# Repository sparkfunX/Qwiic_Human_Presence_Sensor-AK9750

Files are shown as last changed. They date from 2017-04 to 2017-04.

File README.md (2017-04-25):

Qwiic Human Presence Sensor - AK9750
========================================

Qwiic Human Presence Sensor - AK9750

[*SPX-14289*](https://www.sparkfun.com/products/14289)

The AK9750 is a passive infrared sensor with four discrete sensors built into one digital package. PIRs are most often used in security systems to detect the movement of a human talking through the room. If you've ever seen a 1" white sphere in the corner of a room, that's a PIR. We sell a [simple PIR](https://www.sparkfun.com/products/13285) as well. The problem with PIRs is many fold. The vast majority of PIRs use a simple on/off interface. The AK9750 is a digital sensor giving you a 16-bit digital value over I<sup>2</sup>C. Furthermore, the AK9750 has *four* sensors built in! This allows you to detect not only presence but relative distance and direction of movement (for example: PIR2 went off then PIR4 went off so the human is moving left to right).

Each of the four sensors outputs the IR current in pico-amps (-14,286 to 14,286pA). A PIR reading can vary from roughly -200 (no human present) to 1500 when a human is detected standing in front of a given channel but it varies due to environmental factors and other heat sources in view. We've written a library to control the sensor and included a examples showing how to output the sensor readings. We've also written a Processing sketch to visualize the IR sensor readings in real time. 

The Qwiic Human Presence Sensor - AK9750 is rear mounted through the 0.8mm thick PCB. Additionally, the sensor ships without a lens. We've found the sensor to perform quite well and detect human movement over 10 feet (3 meters) away without the standard Fresnel lens. 

Need many eyes in the sky? The ADR jumpers allow up to 3 sensors on a bus. Need more? Our [Qwiic Mux](https://www.sparkfun.com/products/14257) will enable up to 192 sensors for a total of 768 presence readings. Eeek!

This board includes Qwiic connectors. The [Qwiic system](http://www.sparkfun.com/qwiic) enables fast and solderless connection between popular platforms and various sensors and actuators. You can read more about the Qwiic system [here](http://www.sparkfun.com/qwiic).

Repository Contents
-------------------

* **/Documents** - AK9750 datasheet and graph of movement detection. 
* **/Firmware** - Example sketches for the library (.ino). Run these from the Arduino IDE. 
* **/Hardware** - Source files for the PCB layout in EAGLE (.brd, .sch).
* **/Visualizer** - Processing sketch with matching Arduino sketch to see data on a heat map.

License Information
-------------------

This product is _**open source**_!

Please review the LICENSE.md file for license information.

If you have any questions or concerns on licensing, please contact techsupport@sparkfun.com.

Distributed as-is; no warranty is given.

- Your friends at SparkFun.

_<COLLABORATION CREDIT>_

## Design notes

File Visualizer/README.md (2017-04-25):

AK9750 Visualizer
========================================

AK9750 Visualizer Processing Sketch

The visualizer sketch shows four circles. The brightness of the red is based on the IR readings from the AK9750. This is a good way to see how the sensor responds to humans walking through a scene.

There is one line in the sketch that will need to be adapted to your environment:

    sensorValue[x] = map(float(tempValues[x]), -200, 400, 0, 255);

This line maps an IR reading from -200/400 to 0/255 (allowed red colors). Your sensor readings may be lower than -200 and greater than 400 depending on your environment.

License Information
-------------------

This product is _**open source**_!

Please review the LICENSE.md file for license information.

If you have any questions or concerns on licensing, please contact techsupport@sparkfun.com.

Distributed as-is; no warranty is given.

- Your friends at SparkFun.

_<COLLABORATION CREDIT>_

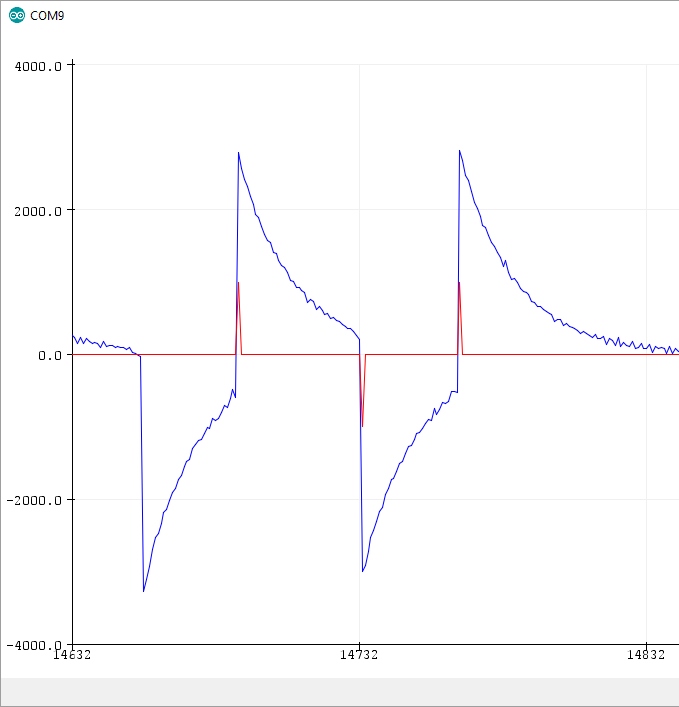
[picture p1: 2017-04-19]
Documents/Presence-Graph.jpg

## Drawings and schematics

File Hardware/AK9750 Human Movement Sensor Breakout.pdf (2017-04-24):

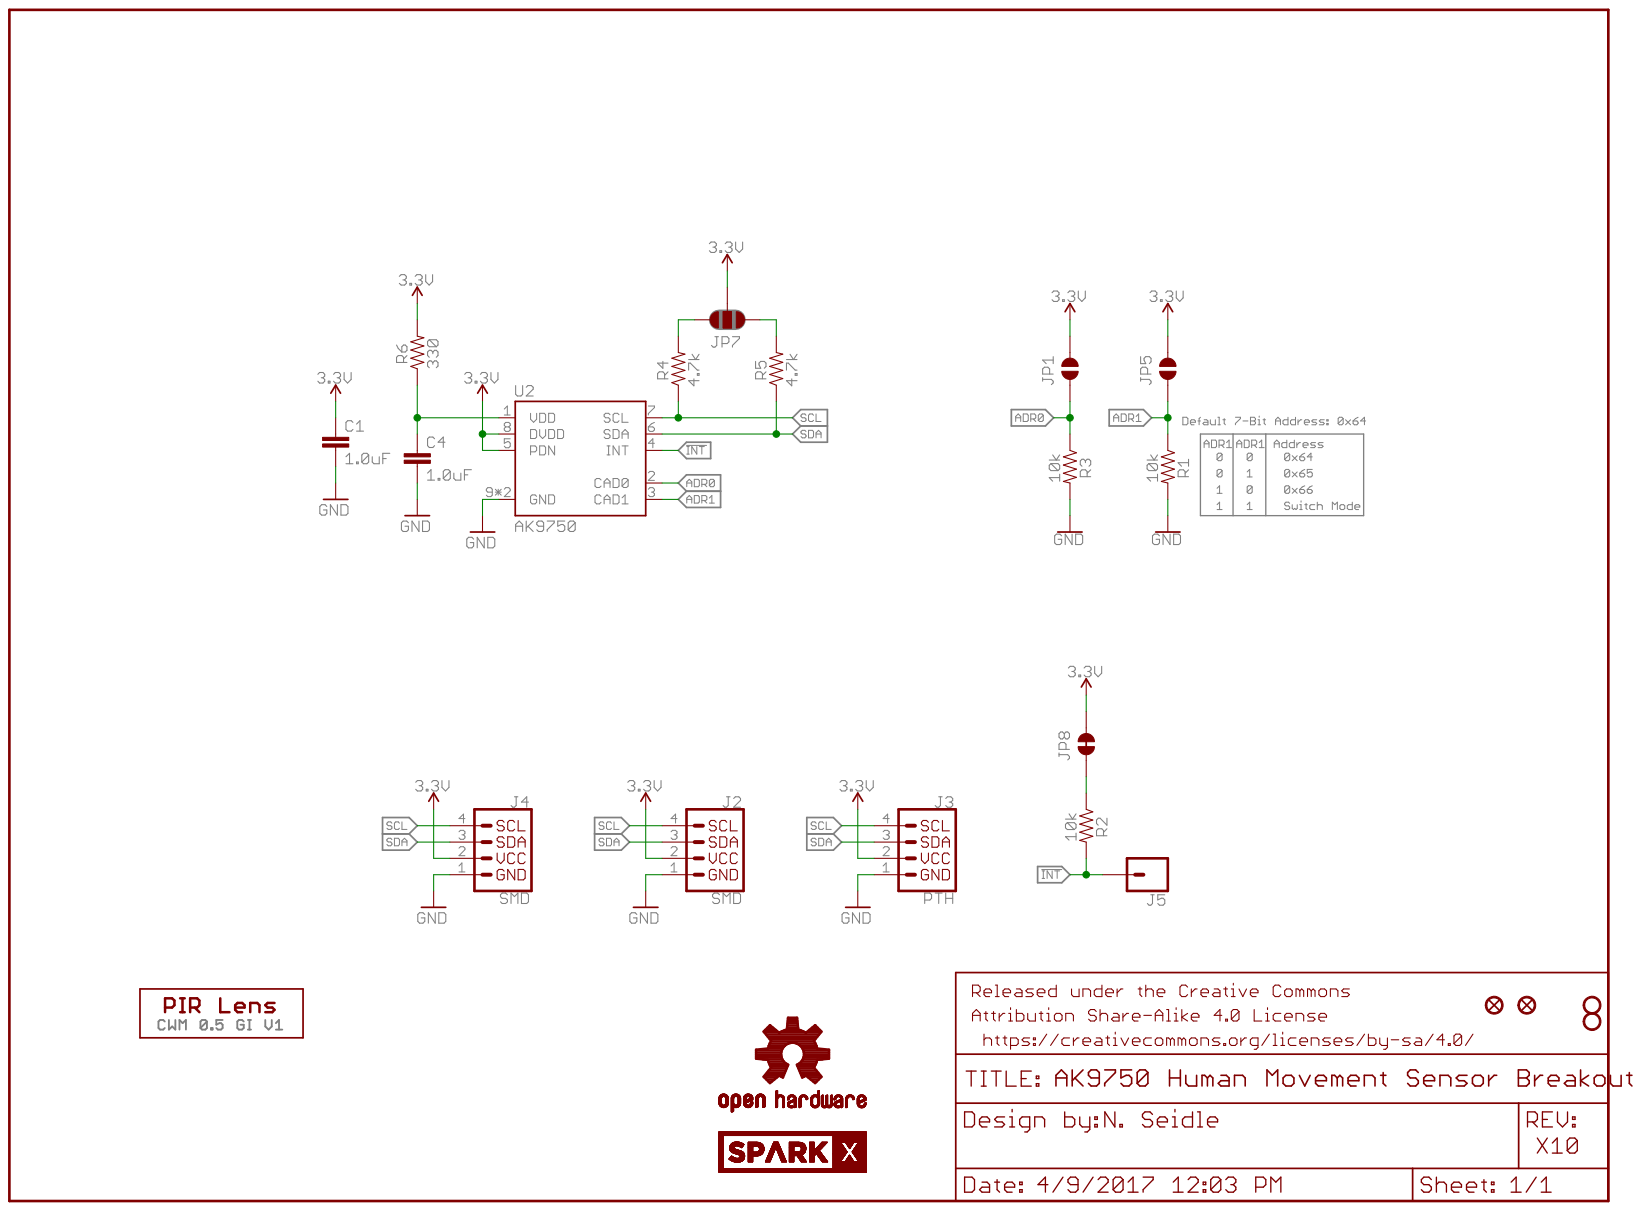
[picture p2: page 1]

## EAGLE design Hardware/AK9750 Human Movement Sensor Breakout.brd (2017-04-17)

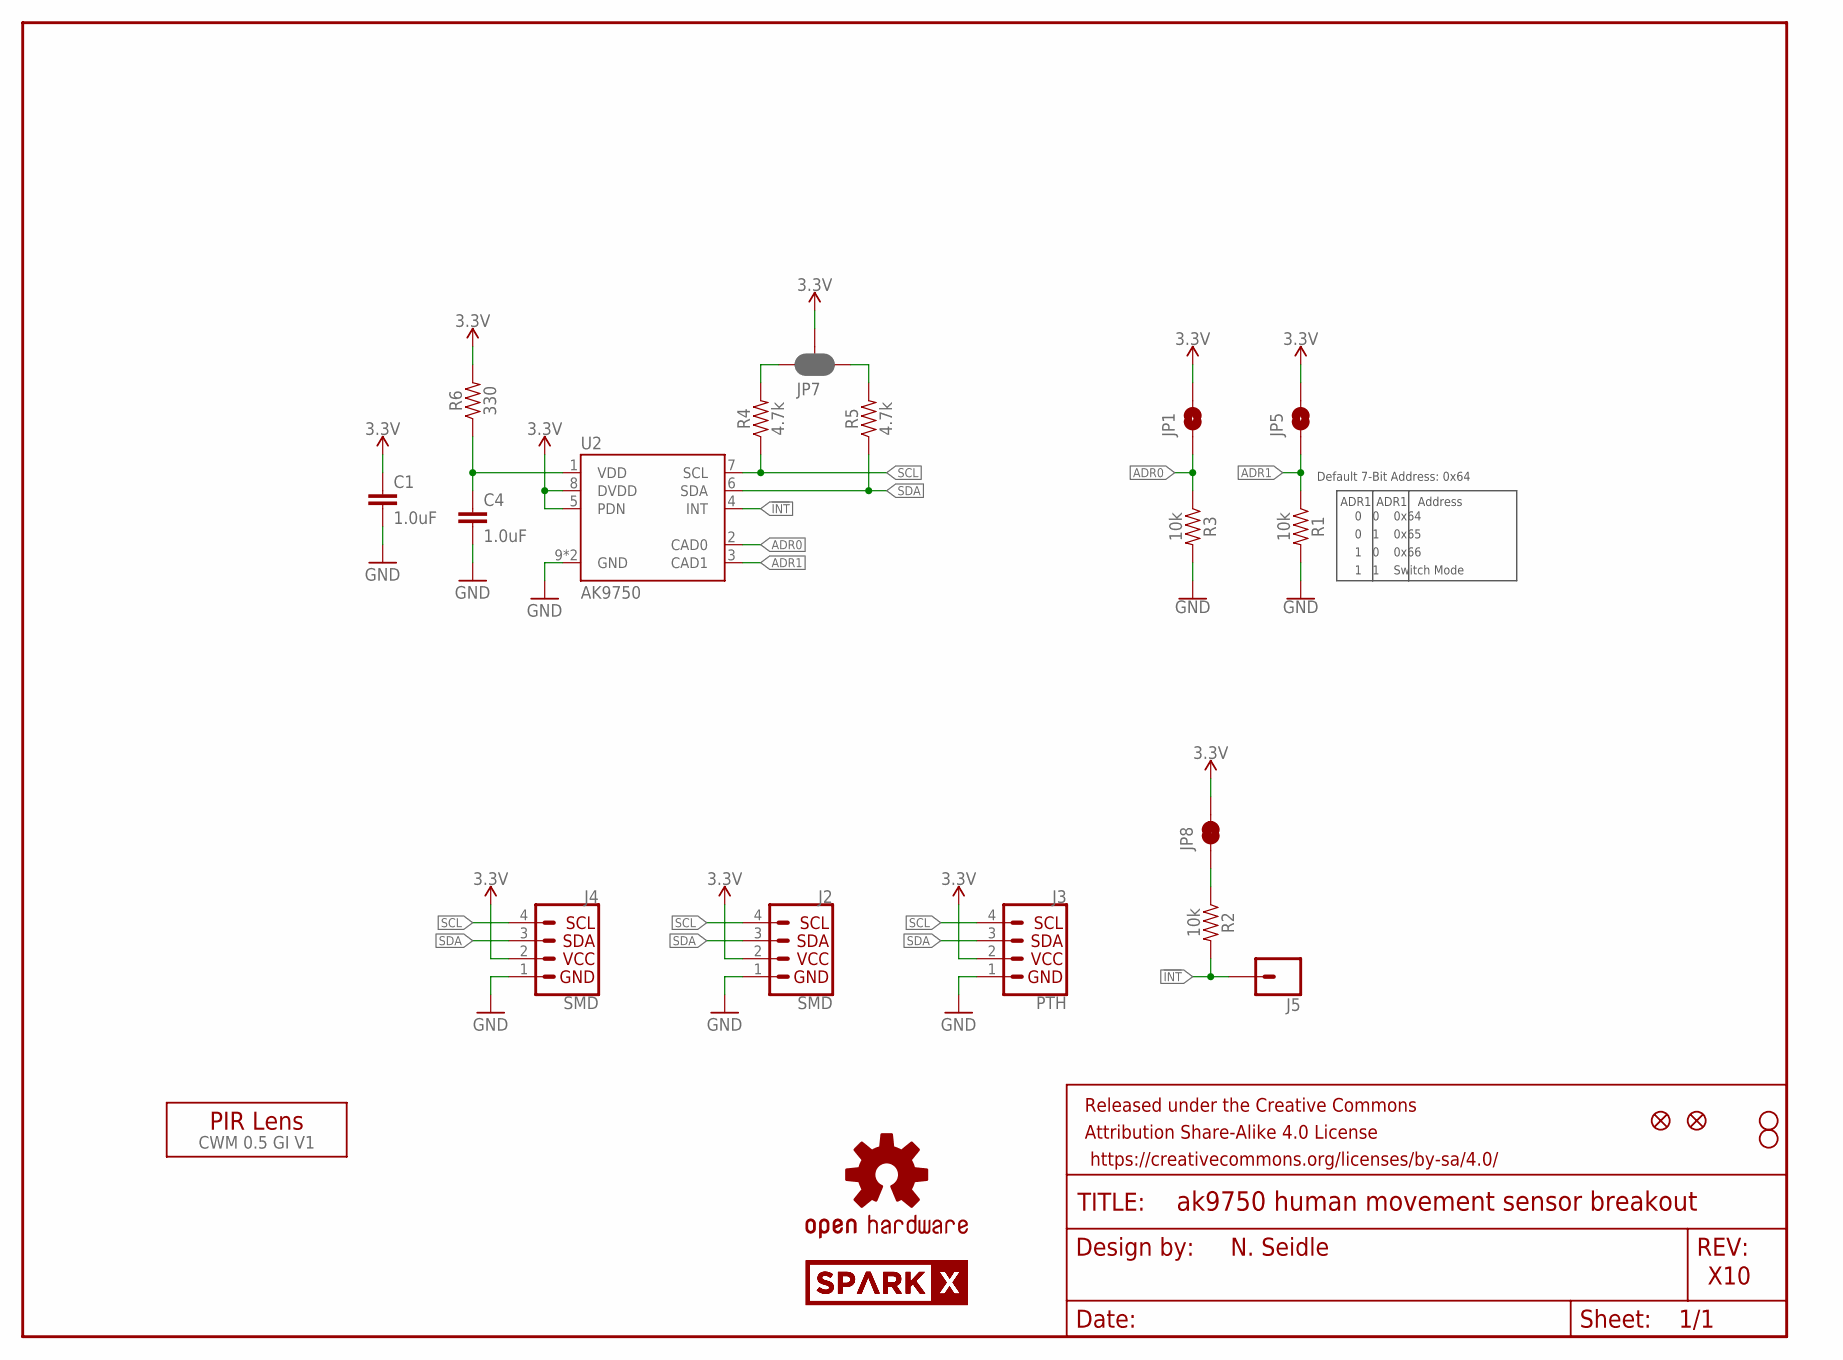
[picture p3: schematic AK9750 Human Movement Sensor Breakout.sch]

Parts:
C1, C4: 1.0uF; 0603
FRAME1: FRAME-LETTER; CREATIVE_COMMONS
J2, J4: SMD; 1X04_1MM_RA
J3: PTH; 1X04_NO_SILK
J5: CONN_01PTH_NO_SILK_YES_STOP; 1X01_NO_SILK
JP1, JP5: JUMPER-SMT_2_NO_SILK; SMT-JUMPER_2_NO_SILK
JP2, JP6: FIDUCIALUFIDUCIAL; MICRO-FIDUCIAL
JP3, JP4: STAND-OFF
JP7: JUMPER-SMT_3_2-NC_PASTE_SILK; SMT-JUMPER_3_2-NC_PASTE_SILK
JP8: JUMPER-SMT_2_NC_TRACE_SILK; SMT-JUMPER_2_NC_TRACE_SILK
LOGO1: OSHW-LOGOMINI; OSHW-LOGO-MINI
R1, R2, R3: 10k; 0603
R4, R5: 4.7k; 0603
R6: 330; 0603
U2: AK9750; SON10
U$1, U$2: SPARKX-LOGO4; SPARKX-MEDIUM
U$3: CWM 0.5 GI V1; LENS-CWM-0.5-GI-V1

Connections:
3.3V: C1.1, J2.2 (VCC), J3.2 (VCC), J4.2 (VCC), JP1.2, JP5.2, JP7.2, JP8.2, R6.2, U2.5 (PDN), U2.8 (DVDD)
!INT: J5.1, R2.2, U2.4 (INT)
ADR0: JP1.1, R3.1, U2.2 (CAD0)
ADR1: JP5.1, R1.1, U2.3 (CAD1)
GND: C1.2, C4.2, J2.1 (GND), J3.1 (GND), J4.1 (GND), R1.2, R3.2, U2.9 (GND), U2.10 (GND)
unnamed: JP7.1, R5.2
unnamed: JP7.3, R4.2
unnamed: JP8.1, R2.1
SCL: J2.4 (SCL), J3.4 (SCL), J4.4 (SCL), R4.1, U2.7 (SCL)
SDA: J2.3 (SDA), J3.3 (SDA), J4.3 (SDA), R5.1, U2.6 (SDA)
VDD: C4.1, R6.1, U2.1 (VDD)

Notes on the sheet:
N. Seidle
X10
Default 7-Bit Address: 0x64
ADR1
0 0 0x64
Address
0 1 0x65
1 0 0x66
1 1 Switch Mode

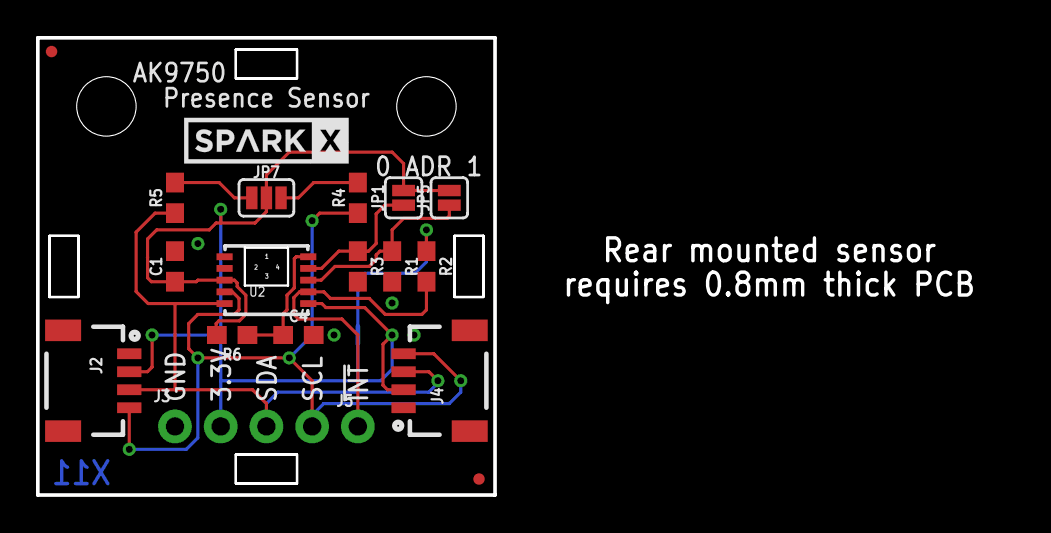
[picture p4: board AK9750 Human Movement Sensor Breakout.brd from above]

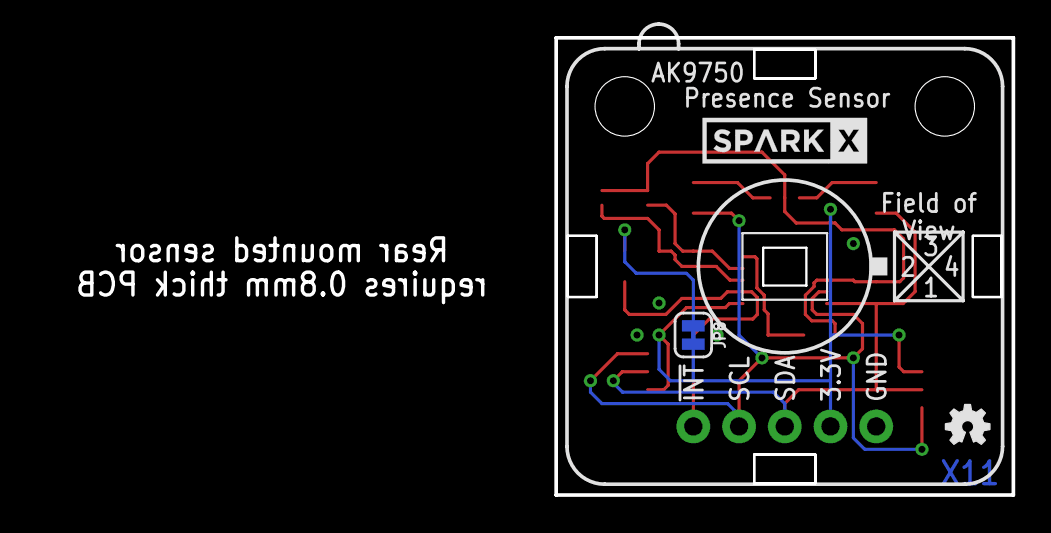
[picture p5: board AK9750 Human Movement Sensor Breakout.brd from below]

Board: 2 copper layers, 25.4 x 25.4 mm, 26 parts (4 on the bottom side), 11 nets.

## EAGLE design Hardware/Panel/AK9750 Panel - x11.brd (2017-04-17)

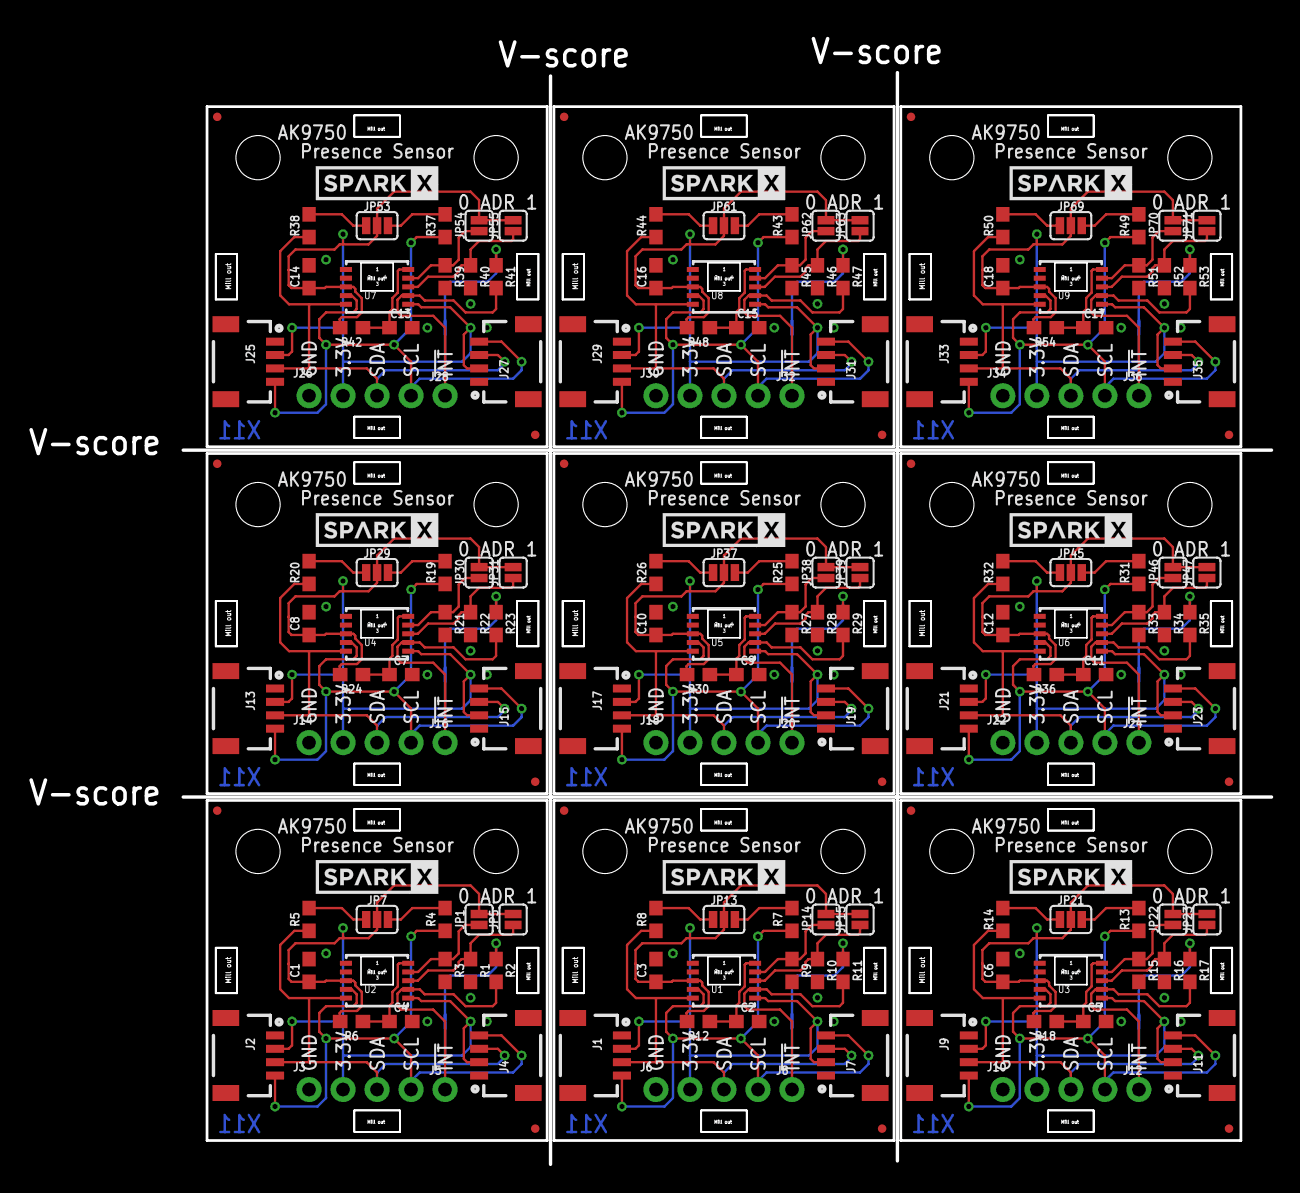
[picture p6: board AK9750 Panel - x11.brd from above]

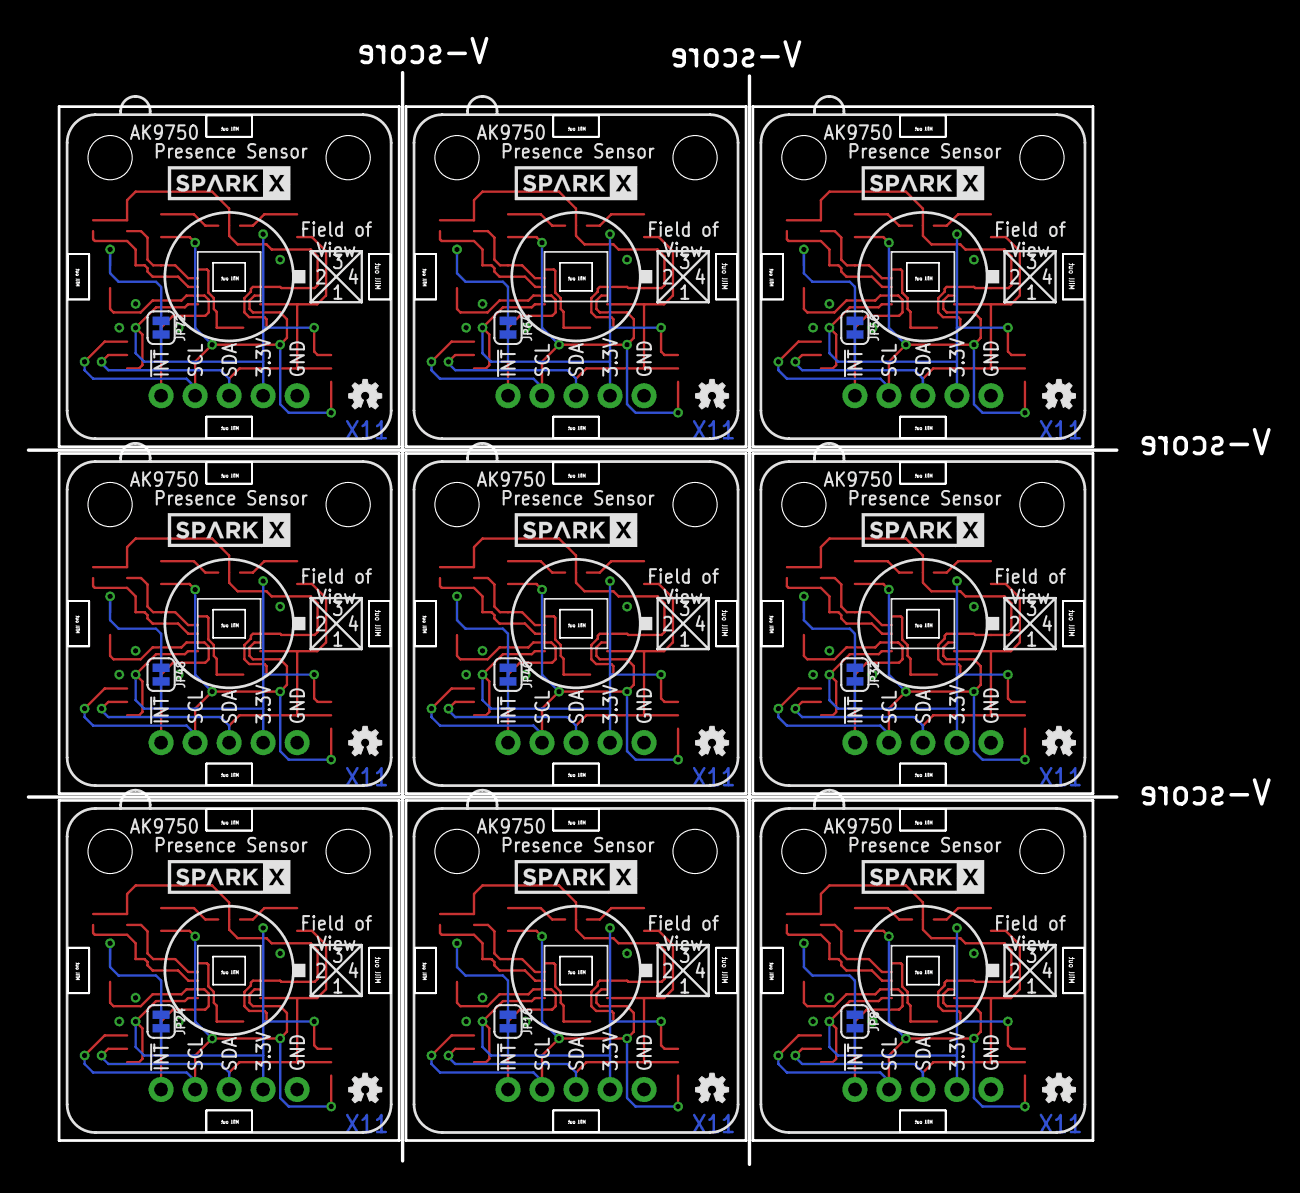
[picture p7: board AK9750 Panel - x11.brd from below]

Board: 2 copper layers, 81.3 x 81.5 mm, 225 parts (36 on the bottom side), 99 nets.

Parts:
C1, C2, C3, C4, C5, C6, C7, C8, C9, C10, C11, C12, C13, C14, C15, C16, C17, C18: 1.0uF; 0603
J1, J2, J4, J7, J9, J11, J13, J15, J17, J19, J21, J23, J25, J27, J29, J31, J33, J35: SMD; 1X04_1MM_RA
J3, J6, J10, J14, J18, J22, J26, J30, J34: PTH; 1X04_NO_SILK
J5, J8, J12, J16, J20, J24, J28, J32, J36: 1X01_NO_SILK
JP1, JP5, JP14, JP15, JP22, JP23, JP30, JP31, JP38, JP39, JP46, JP47, JP54, JP55, JP62, JP63, JP70, JP71: SMT-JUMPER_2_NO_SILK
JP2, JP6, JP11, JP12, JP19, JP20, JP27, JP28, JP35, JP36, JP43, JP44, JP51, JP52, JP59, JP60, JP67, JP68: FIDUCIALUFIDUCIAL; MICRO-FIDUCIAL
JP3, JP4, JP9, JP10, JP17, JP18, JP25, JP26, JP33, JP34, JP41, JP42, JP49, JP50, JP57, JP58, JP65, JP66: STAND-OFF
JP7, JP13, JP21, JP29, JP37, JP45, JP53, JP61, JP69: SMT-JUMPER_3_2-NC_PASTE_SILK
JP8, JP16, JP24, JP32, JP40, JP48, JP56, JP64, JP72: SMT-JUMPER_2_NC_TRACE_SILK
LOGO1, LOGO2, LOGO3, LOGO4, LOGO5, LOGO6, LOGO7, LOGO8, LOGO9: OSHW-LOGOMINI; OSHW-LOGO-MINI
R1, R2, R3, R9, R10, R11, R15, R16, R17, R21, R22, R23, R27, R28, R29, R33, R34, R35, R39, R40, R41, R45, R46, R47, R51, R52, R53: 10k; 0603
R4, R5, R7, R8, R13, R14, R19, R20, R25, R26, R31, R32, R37, R38, R43, R44, R49, R50: 4.7k; 0603
R6, R12, R18, R24, R30, R36, R42, R48, R54: 330; 0603
U1, U2, U3, U4, U5, U6, U7, U8, U9: AK9750; SON10
U$1, U$2, U$4, U$5, U$7, U$8, U$10, U$11, U$13, U$14, U$16, U$17, U$19, U$20, U$22, U$23, U$25, U$26: SPARKX-LOGO4; SPARKX-MEDIUM
U$3, U$6, U$9, U$12, U$15, U$18, U$21, U$24, U$27: CWM 0.5 GI V1; LENS-CWM-0.5-GI-V1

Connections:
3.3V: C1.1, J2.2, J3.2, J4.2, JP1.2, JP5.2, JP7.2, JP8.2, R6.2, U2.5, U2.8
3.3V1: C3.1, J1.2, J6.2, J7.2, JP13.2, JP14.2, JP15.2, JP16.2, R12.2, U1.5, U1.8
3.3V2: C6.1, J9.2, J10.2, J11.2, JP21.2, JP22.2, JP23.2, JP24.2, R18.2, U3.5, U3.8
3.3V3: C8.1, J13.2, J14.2, J15.2, JP29.2, JP30.2, JP31.2, JP32.2, R24.2, U4.5, U4.8
3.3V4: C10.1, J17.2, J18.2, J19.2, JP37.2, JP38.2, JP39.2, JP40.2, R30.2, U5.5, U5.8
3.3V5: C12.1, J21.2, J22.2, J23.2, JP45.2, JP46.2, JP47.2, JP48.2, R36.2, U6.5, U6.8
3.3V6: C14.1, J25.2, J26.2, J27.2, JP53.2, JP54.2, JP55.2, JP56.2, R42.2, U7.5, U7.8
3.3V7: C16.1, J29.2, J30.2, J31.2, JP61.2, JP62.2, JP63.2, JP64.2, R48.2, U8.5, U8.8
3.3V8: C18.1, J33.2, J34.2, J35.2, JP69.2, JP70.2, JP71.2, JP72.2, R54.2, U9.5, U9.8
!INT: J5.1, R2.2, U2.4
!INT1: J8.1, R11.2, U1.4
!INT2: J12.1, R17.2, U3.4
!INT3: J16.1, R23.2, U4.4
!INT4: J20.1, R29.2, U5.4
!INT5: J24.1, R35.2, U6.4
!INT6: J28.1, R41.2, U7.4
!INT7: J32.1, R47.2, U8.4
!INT8: J36.1, R53.2, U9.4
ADR0: JP1.1, R3.1, U2.2
ADR1: JP5.1, R1.1, U2.3
ADR2: JP14.1, R9.1, U1.2
ADR3: JP15.1, R10.1, U1.3
ADR4: JP22.1, R15.1, U3.2
ADR5: JP23.1, R16.1, U3.3
ADR6: JP30.1, R21.1, U4.2
ADR7: JP31.1, R22.1, U4.3
ADR8: JP38.1, R27.1, U5.2
ADR9: JP39.1, R28.1, U5.3
ADR10: JP46.1, R33.1, U6.2
ADR11: JP47.1, R34.1, U6.3
ADR12: JP54.1, R39.1, U7.2
ADR13: JP55.1, R40.1, U7.3
ADR14: JP62.1, R45.1, U8.2
ADR15: JP63.1, R46.1, U8.3
ADR16: JP70.1, R51.1, U9.2
ADR17: JP71.1, R52.1, U9.3
GND9: C1.2, C4.2, J2.1, J3.1, J4.1, R1.2, R3.2, U2.9, U2.10
GND10: C2.2, C3.2, J1.1, J6.1, J7.1, R9.2, R10.2, U1.9, U1.10
GND11: C5.2, C6.2, J9.1, J10.1, J11.1, R15.2, R16.2, U3.9, U3.10
GND12: C7.2, C8.2, J13.1, J14.1, J15.1, R21.2, R22.2, U4.9, U4.10
GND13: C9.2, C10.2, J17.1, J18.1, J19.1, R27.2, R28.2, U5.9, U5.10
GND14: C11.2, C12.2, J21.1, J22.1, J23.1, R33.2, R34.2, U6.9, U6.10
GND15: C13.2, C14.2, J25.1, J26.1, J27.1, R39.2, R40.2, U7.9, U7.10
GND16: C15.2, C16.2, J29.1, J30.1, J31.1, R45.2, R46.2, U8.9, U8.10
GND17: C17.2, C18.2, J33.1, J34.1, J35.1, R51.2, R52.2, U9.9, U9.10
unnamed: JP7.1, R5.2
unnamed: JP7.3, R4.2
unnamed: JP8.1, R2.1
unnamed: JP13.1, R8.2
unnamed: JP13.3, R7.2
unnamed: JP16.1, R11.1
unnamed: JP21.1, R14.2
unnamed: JP21.3, R13.2
unnamed: JP24.1, R17.1
unnamed: JP29.1, R20.2
unnamed: JP29.3, R19.2
unnamed: JP32.1, R23.1
unnamed: JP37.1, R26.2
unnamed: JP37.3, R25.2
unnamed: JP40.1, R29.1
unnamed: JP45.1, R32.2
unnamed: JP45.3, R31.2
unnamed: JP48.1, R35.1
unnamed: JP53.1, R38.2
unnamed: JP53.3, R37.2
unnamed: JP56.1, R41.1
unnamed: JP61.1, R44.2
unnamed: JP61.3, R43.2
unnamed: JP64.1, R47.1
unnamed: JP69.1, R50.2
unnamed: JP69.3, R49.2
unnamed: JP72.1, R53.1
SCL: J2.4, J3.4, J4.4, R4.1, U2.7
SCL1: J1.4, J6.4, J7.4, R7.1, U1.7
SCL2: J9.4, J10.4, J11.4, R13.1, U3.7
SCL3: J13.4, J14.4, J15.4, R19.1, U4.7
SCL4: J17.4, J18.4, J19.4, R25.1, U5.7
SCL5: J21.4, J22.4, J23.4, R31.1, U6.7
SCL6: J25.4, J26.4, J27.4, R37.1, U7.7
SCL7: J29.4, J30.4, J31.4, R43.1, U8.7
SCL8: J33.4, J34.4, J35.4, R49.1, U9.7
SDA: J2.3, J3.3, J4.3, R5.1, U2.6
SDA1: J1.3, J6.3, J7.3, R8.1, U1.6
SDA2: J9.3, J10.3, J11.3, R14.1, U3.6
SDA3: J13.3, J14.3, J15.3, R20.1, U4.6
SDA4: J17.3, J18.3, J19.3, R26.1, U5.6
SDA5: J21.3, J22.3, J23.3, R32.1, U6.6
SDA6: J25.3, J26.3, J27.3, R38.1, U7.6
SDA7: J29.3, J30.3, J31.3, R44.1, U8.6
SDA8: J33.3, J34.3, J35.3, R50.1, U9.6
VDD: C4.1, R6.1, U2.1
VDD1: C2.1, R12.1, U1.1
VDD2: C5.1, R18.1, U3.1
VDD3: C7.1, R24.1, U4.1
VDD4: C9.1, R30.1, U5.1
VDD5: C11.1, R36.1, U6.1
VDD6: C13.1, R42.1, U7.1
VDD7: C15.1, R48.1, U8.1
VDD8: C17.1, R54.1, U9.1

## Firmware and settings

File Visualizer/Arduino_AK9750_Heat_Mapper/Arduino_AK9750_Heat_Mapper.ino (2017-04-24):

/*
  AK9752 Human Presence and Movement Sensor Visualizer
  By: Nathan Seidle
  SparkFun Electronics
  Date: March 10th, 2017
  License: This code is public domain but you buy me a beer if you use this and we meet someday (Beerware license).

  Outputs the four IR readings and internal temperature.

  Used in conjunction with Processing app to visualize the data on a computer.

  IR readings increase as warm bodies enter into the observable areas.

  Hardware Connections:
  Attach a Qwiic shield to your RedBoard or Uno.
  Plug the Qwiic sensor into any port.
  Serial.print it out at 9600 baud to serial monitor.
*/

#include <Wire.h>

#include "SparkFun_AK9750_Arduino_Library.h"

AK9750 movementSensor; //Hook object to the library

int ir1, ir2, ir3, ir4, temperature;

void setup()
{
  Serial.begin(9600);

  Wire.begin();

  //Turn on sensor
  if (movementSensor.begin() == false)
  {
    Serial.println("Device not found. Check wiring.");
    while (1);
  }
}

void loop()
{
  if (movementSensor.available())
  {
    ir1 = movementSensor.getIR1(); //Lower
    ir2 = movementSensor.getIR2(); //Left
    ir3 = movementSensor.getIR3(); //Upper
    ir4 = movementSensor.getIR4(); //Right
    float tempF = movementSensor.getTemperatureF();

    movementSensor.refresh(); //Read dummy register after new data is read

    //Note: The observable area is shown in the silkscreen.
    //If sensor 2 increases first, the human is on the left
    Serial.print(ir1);
    Serial.print(",");
    Serial.print(ir2);
    Serial.print(",");
    Serial.print(ir3);
    Serial.print(",");
    Serial.print(ir4);
    Serial.print(",");
    Serial.print(tempF);
    Serial.println();
  }

  delay(50);
}

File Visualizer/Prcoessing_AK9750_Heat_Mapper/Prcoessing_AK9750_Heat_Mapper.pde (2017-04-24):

/*
  Demo the four IR sensors on the AK9750 on a heat map
  By: Nathan Seidle
  SparkFun Electronics
  Date: April 24th, 2017
  License: This code is public domain but you buy me a beer if you use this and we meet someday (Beerware license).

  This processing sketch demonstrates how to read the four IR values from the AK9750 and 
  display them in a four quadrant heat map.
  
  You'll need the AK9750 hooked up to an Arduino and running the "Arduino_AK9750_Heat_Mapper.ino" sketch. 
*/

import processing.serial.*;

Serial myPort;

float[] sensorValue = new float[4];

int windowX = 1000; //Make these values match the size() call in setup()
int windowY = 1000;

int ballSize = windowX / 2;

//Data comes in as:
//sensorValue[0] is lower
//sensorValue[1] is left
//sensorValue[2] is upper
//sensorValue[3] is right

int ballLocation0X = windowX / 2; //Lower
int ballLocation0Y = windowY / 4 * 3;

int ballLocation1X = windowX / 4; //Left
int ballLocation1Y = windowY / 2;

int ballLocation2X = windowX / 2; //Upper
int ballLocation2Y = windowY / 4;

int ballLocation3X = windowX / 4 * 3; //Right
int ballLocation3Y = windowY / 2;

void setup()
{
  size(1000, 1000); //Set this to whatever screen size you'd like

  //Initialize your serial port and set the baud rate to 9600
  myPort = new Serial(this, Serial.list()[2], 9600); //You may need to set your comm port to 0, 1, etc
  myPort.bufferUntil('\n');
}

void draw()
{
  background(0); //Clear screen

  //Draw the heat circles and color them based on incoming sensor values
  fill( int(sensorValue[0]), 0, 0 );
  ellipse(ballLocation0X, ballLocation0Y, ballSize, ballSize);

  fill( int(sensorValue[1]), 0, 0 );
  ellipse(ballLocation1X, ballLocation1Y, ballSize, ballSize);

  fill( int(sensorValue[2]), 0, 0 );
  ellipse(ballLocation2X, ballLocation2Y, ballSize, ballSize);

  fill( int(sensorValue[3]), 0, 0 );
  ellipse(ballLocation3X, ballLocation3Y, ballSize, ballSize);
}

//If there is incoming serial, parse it and load it into the sensorValue array
void serialEvent(Serial myPort) {

  String val = myPort.readStringUntil('\n');

  if (val != null) 
  {
    val = trim(val); //Trim whitespace and formatting characters
    println(val); //Print the incoming string for debugging

    String tempValues[] = split(val, ',');

    for (int x = 0; x < 4; x++)
    {
      //Convert the string into an int that is mapped
      //-200 to 400 works well but play with it
      sensorValue[x] = map(float(tempValues[x]), -200, 400, 0, 255);
    }

  }
}

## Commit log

2017-04-09 Added lens FP. Increased aperature for IR sensor.
    [AK9750 Human Movement Sensor Breakout.brd, AK9750 Human Movement Sensor Breakout.sch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]
2017-04-17 Adding panel files
    [AK9750 Human Movement Sensor Breakout.brd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]
2017-04-24 Adding processing heat mapper example

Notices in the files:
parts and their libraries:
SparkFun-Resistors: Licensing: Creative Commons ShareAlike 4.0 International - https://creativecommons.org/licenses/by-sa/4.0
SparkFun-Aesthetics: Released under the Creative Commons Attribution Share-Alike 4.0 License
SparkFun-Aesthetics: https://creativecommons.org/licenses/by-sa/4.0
